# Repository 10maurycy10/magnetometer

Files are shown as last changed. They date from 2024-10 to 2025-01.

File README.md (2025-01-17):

# Fluxgate magnetometer datalogger

Data is logged to a microSD/SDHC/SDXC card, which must support SPI mode.
It should be formated as FAT12, FAT16, FAT32 or ExFAT.
If it has an MBR partion table, the first partion will be used.

Most sub 2 TB cards should work as is.

Data is logged to `FLUXGATE.CSV`, in a CSV format.

|First field|Second field format|Notes|
|-|-|-|
|empty string|empty string|Startup banner, includes third field with human readable comment|
|`Vdiv`|Int (mV)|Measured voltage on the Vdd/2 rail of the opamp filter, written on startup.|
|`Vamp`|Int (mV)|Measured amplifier output voltage, written on startup|
|`Vdiv`|Int (mV)|Measure diffence between Vdd/2 and output, written on startup|
|`OSR`|Int|Oversampling ratio used for measurements|
|`Tlog`|Int (ms)|Time between measurements|
|Int|Int|Field measurements, first field is a counter that increments with each one.|

$$ \text{Reading} = \text{Peak-Peak voltage (mV)} \times 10 \times \text{OSR} $$

# Hardware

It should be able to drive most fluxgates, but I got the best result with a [high permiability, square-loop core](https://www.digikey.com/en/products/detail/toshiba-semiconductor-and-storage/MS21X14X4-5W/4701157)
using the classic ring core configuration:
The drive coil was wound around the entire core, and the sense coil was wound on a 3d printed bobin placed over the core:

 
 
With the high gain of the amplifier, the earth's magnetic field (50 uT at my place) is enough to saturate the sensor. 
Alternativly, the compensation driver can be enabled to cancel out the field, but the driver can only push current in one direction, so the sensor might have to be flipped for this to work.

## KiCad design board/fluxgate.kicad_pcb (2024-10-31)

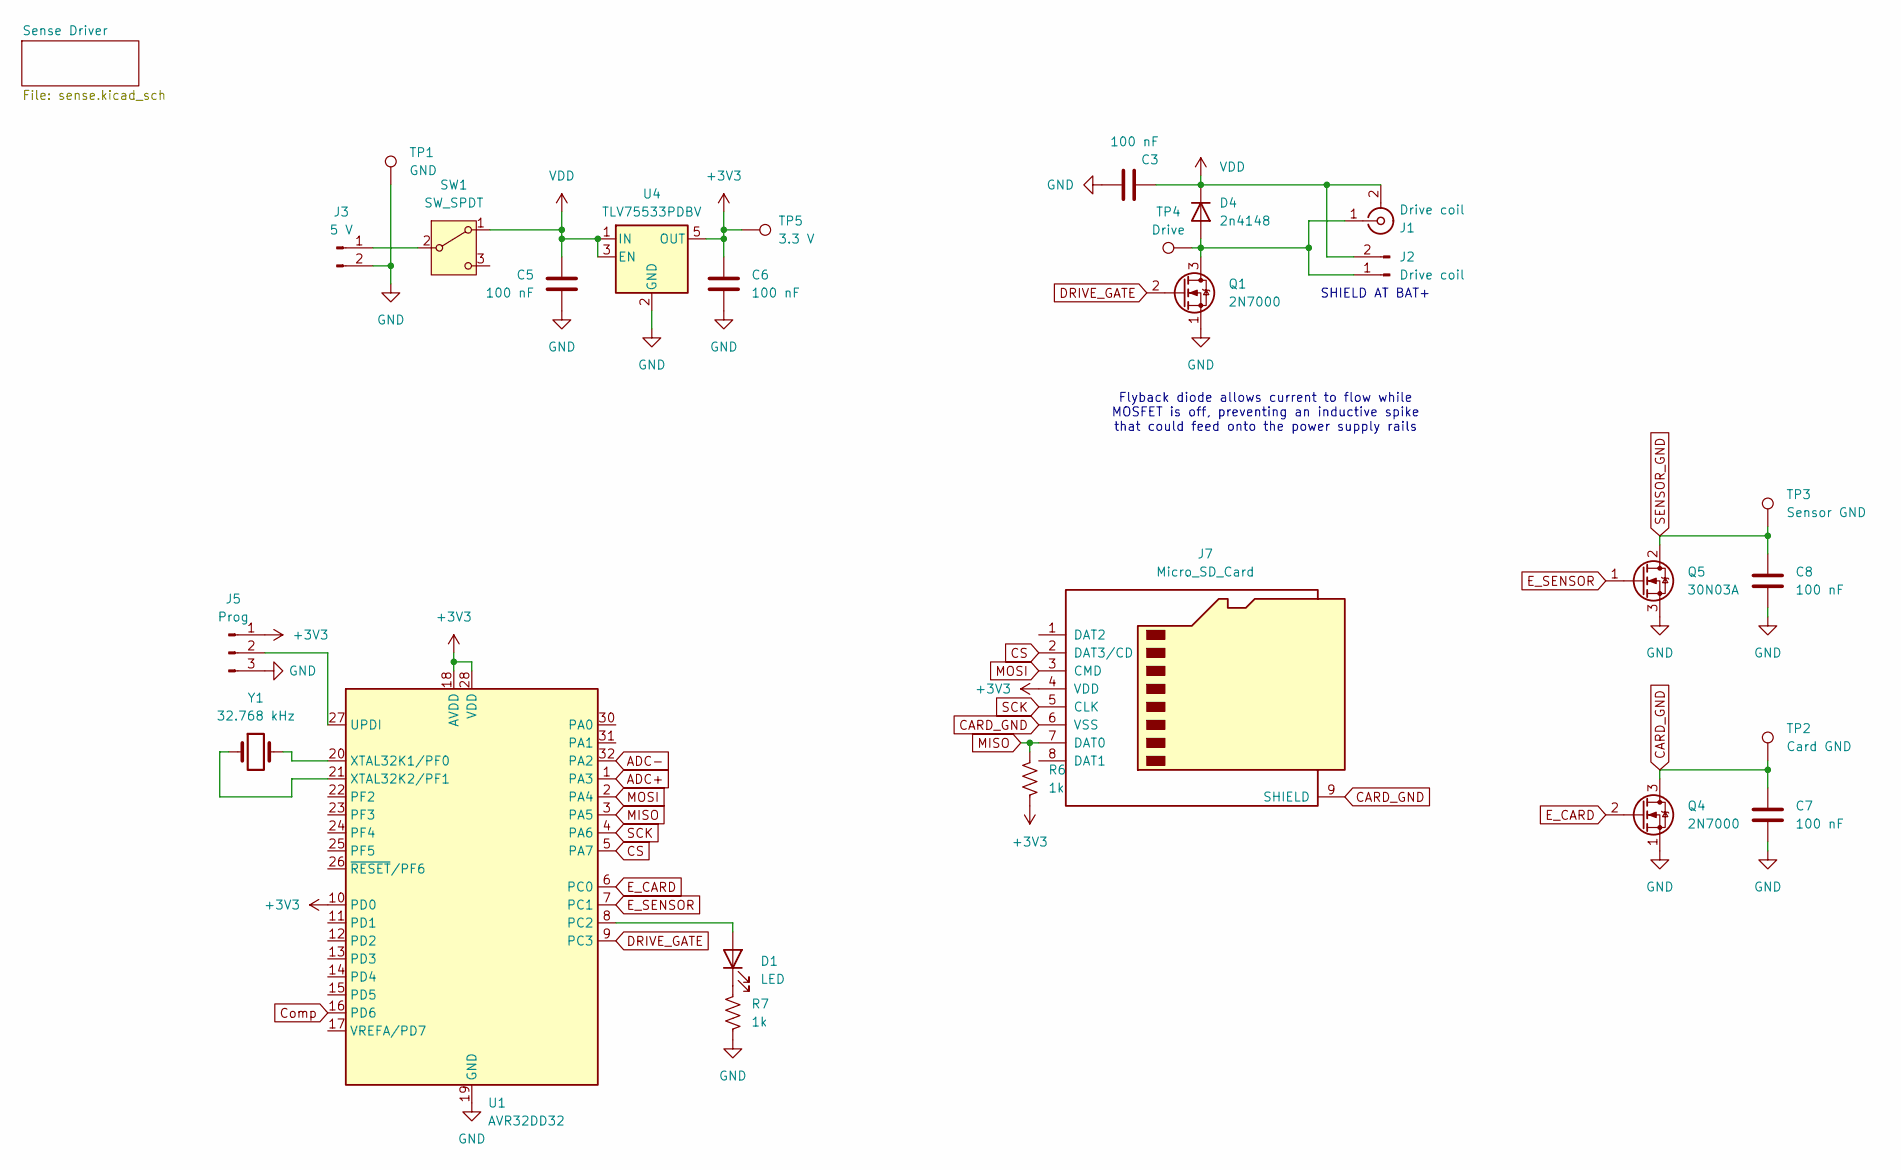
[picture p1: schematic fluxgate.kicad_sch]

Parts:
C3, C5, C6, C7, C8: 100 nF; C_Disc_D3.4mm_W2.1mm_P2.50mm
D1: LED; LED_D3.0mm
D4: 2n4148; D_DO-34_SOD68_P7.62mm_Horizontal
J1: Drive coil; SMA_Amphenol_132289_EdgeMount
J2: Drive coil; PinHeader_1x02_P2.54mm_Vertical
J3: 5 V; PinHeader_1x02_P2.54mm_Vertical
J5: Prog; PinHeader_1x03_P2.54mm_Vertical
J7: Micro_SD_Card; microSD_HC_Molex_104031-0811
Q1, Q4: 2N7000; TO-92_Inline
Q5: 30N03A; TO-252-2
R6, R7: 1k; R_Axial_DIN0207_L6.3mm_D2.5mm_P10.16mm_Horizontal
SW1: SW_SPDT; SW_E-Switch_EG1271_SPDT
TP1: GND; TestPoint_Keystone_5015_Micro-Minature
TP2: Card GND; TestPoint_Keystone_5015_Micro-Minature
TP3: Sensor GND; TestPoint_Keystone_5015_Micro-Minature
TP4: Drive; TestPoint_Keystone_5015_Micro-Minature
TP5: 3.3 V; TestPoint_Keystone_5015_Micro-Minature
U1: AVR32DD32; TQFP-32_7x7mm_P0.8mm
U4: TLV75533PDBV; SOT-23-5
Y1: 32.768 kHz; Crystal_HC52-8mm_Vertical

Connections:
+3V3: C6.2, J5.1, J7.4 (VDD), R6.2, TP5.1, U1.10 (PD0), U1.18 (AVDD), U1.28 (VDD), U4.5 (OUT); also elsewhere on the board
ADC+: U1.1 (PA3); also elsewhere on the board
ADC-: U1.32 (PA2); also elsewhere on the board
CARD_GND: C7.1, J7.6 (VSS), J7.9 (SHIELD), Q4.3 (D), TP2.1
CS: J7.2 (DAT3/CD), U1.5 (PA7)
Comp: U1.16 (PD6); also elsewhere on the board
DRIVE_GATE: Q1.2 (G), U1.9 (PC3)
E_CARD: Q4.2 (G), U1.6 (PC0)
E_SENSOR: Q5.1 (G), U1.7 (PC1)
GND: C3.2, C5.1, C6.1, C7.2, C8.2, J3.2, J5.3, Q1.1 (S), Q4.1 (S), Q5.3 (S), R7.2, TP1.1, U1.19 (GND), U1.29 (GND), U4.2 (GND); also elsewhere on the board
MISO: J7.7 (DAT0), R6.1, U1.3 (PA5)
MOSI: J7.3 (CMD), U1.2 (PA4)
unnamed: D1.2 (A), U1.8 (PC2)
unnamed: D1.1 (K), R7.1
unnamed: D4.2 (A), J1.1 (In), J2.1, Q1.3 (D), TP4.1
unnamed: J3.1, SW1.2 (B)
unnamed: J5.2, U1.27 (UPDI)
unnamed: U1.20 (XTAL32K1/PF0), Y1.2
unnamed: U1.21 (XTAL32K2/PF1), Y1.1
SCK: J7.5 (CLK), U1.4 (PA6)
SENSOR_GND: C8.1, Q5.2 (D), TP3.1; also elsewhere on the board
VDD: C3.1, C5.2, D4.1 (K), J1.2 (Ext), J2.2, SW1.1 (A), U4.1 (IN), U4.3 (EN)

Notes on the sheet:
SHIELD AT BAT+
Flyback diode allows current to flow while MOSFET is off, preventing an inductive spike that could feed onto the power supply rails

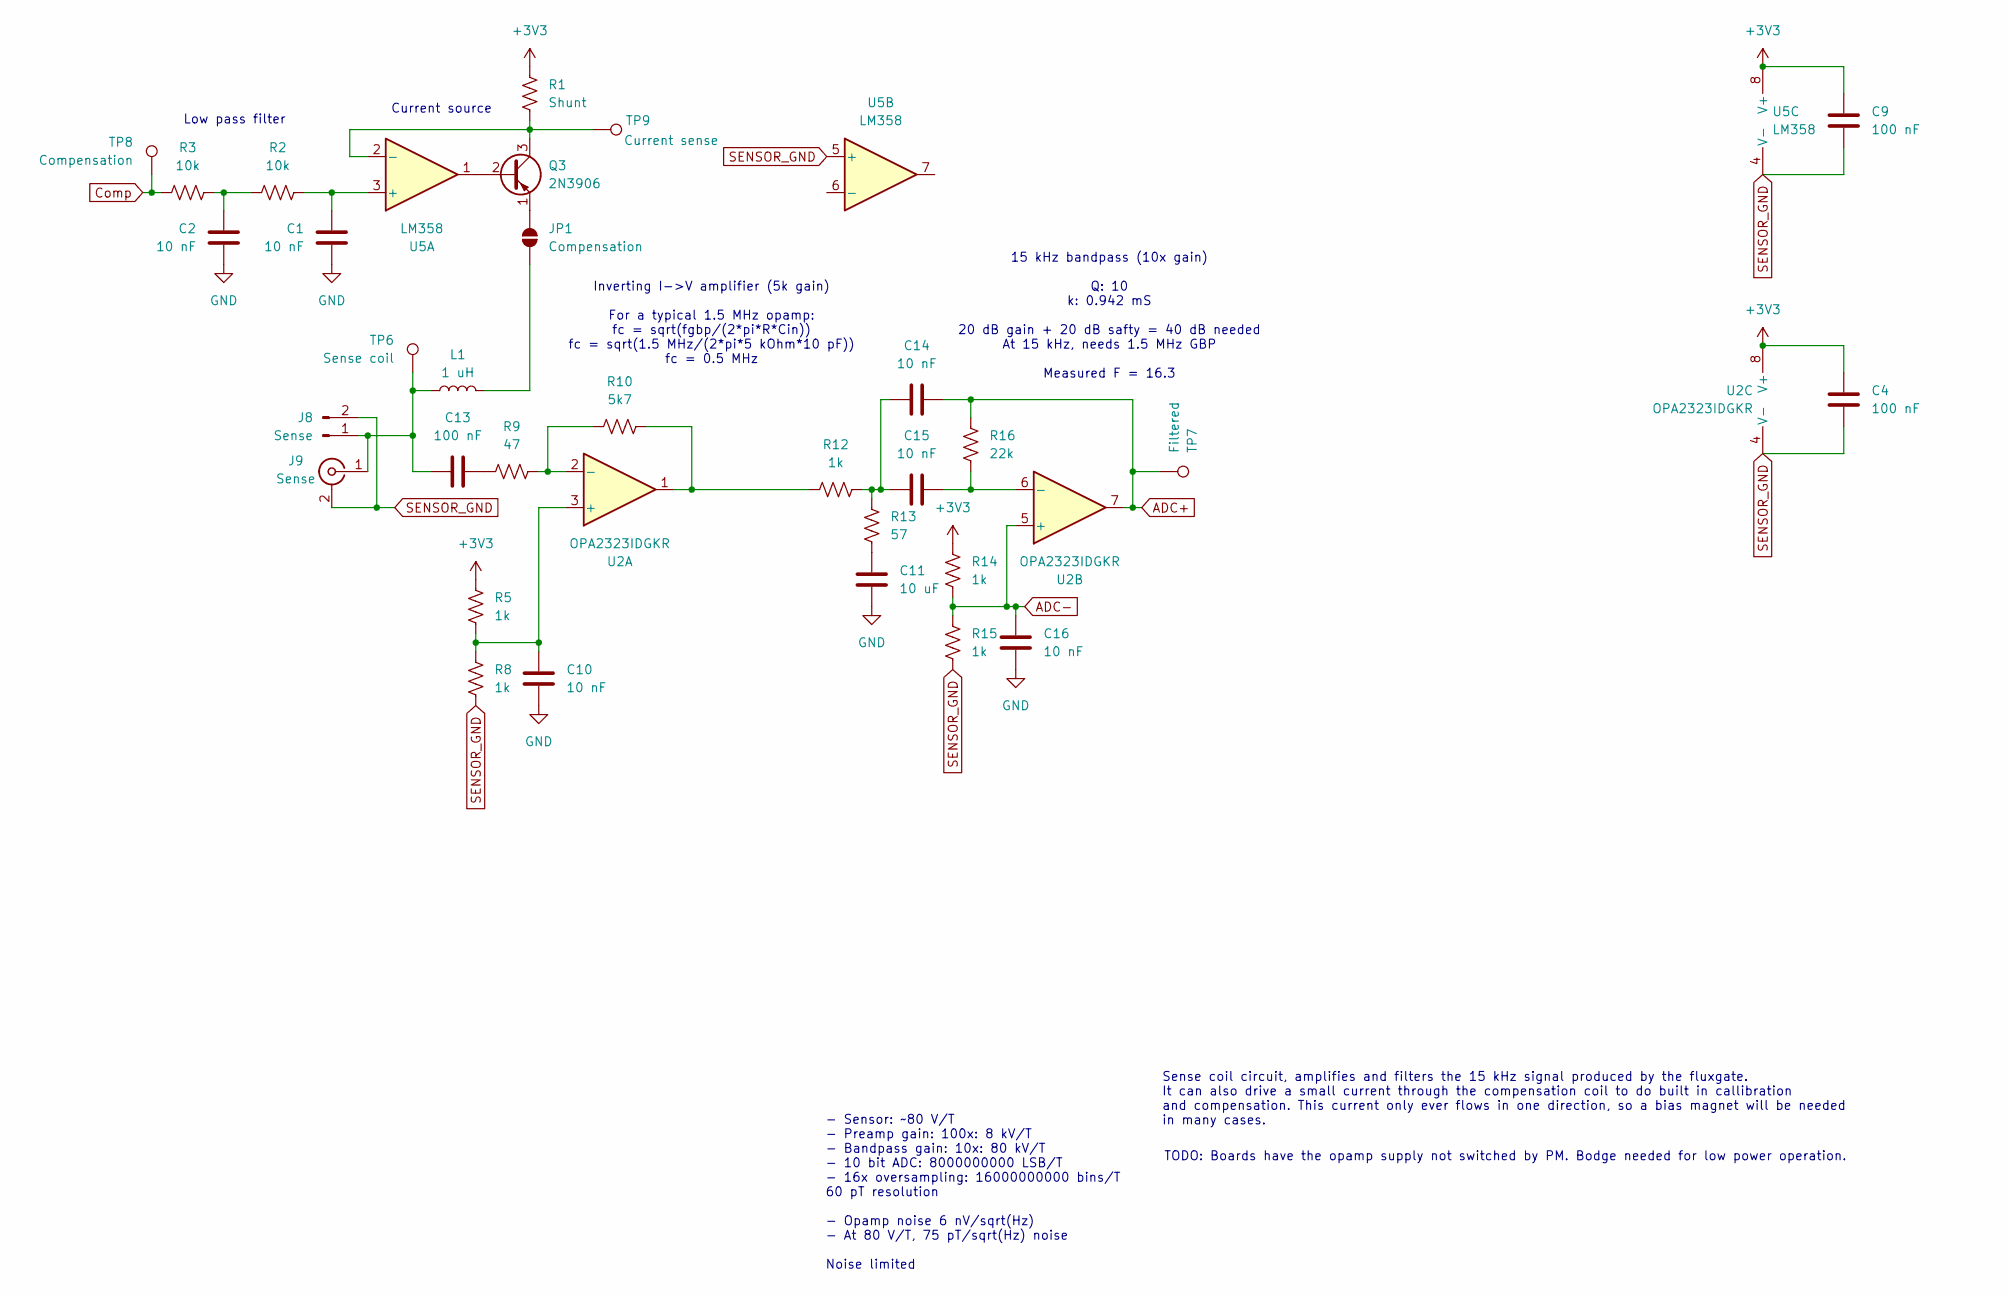
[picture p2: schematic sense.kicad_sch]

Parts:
C1, C2, C10, C14, C15, C16: 10 nF; C_Disc_D3.4mm_W2.1mm_P2.50mm
C4, C9, C13: 100 nF; C_Disc_D3.4mm_W2.1mm_P2.50mm
C11: 10 uF; C_Disc_D3.4mm_W2.1mm_P2.50mm
J8: Sense; PinHeader_1x02_P2.54mm_Vertical
J9: Sense; SMA_Amphenol_132289_EdgeMount
JP1: Compensation; SolderJumper-2_P1.3mm_Open_RoundedPad1.0x1.5mm
L1: 1 uH; L_Radial_D7.2mm_P3.00mm_Murata_1700
Q3: 2N3906; TO-92_Inline
R1: Shunt; R_Axial_DIN0207_L6.3mm_D2.5mm_P10.16mm_Horizontal
R2, R3: 10k; R_Axial_DIN0207_L6.3mm_D2.5mm_P10.16mm_Horizontal
R5, R8, R12, R14, R15: 1k; R_Axial_DIN0207_L6.3mm_D2.5mm_P10.16mm_Horizontal
R9: 47; R_Axial_DIN0207_L6.3mm_D2.5mm_P10.16mm_Horizontal
R10: 5k7; R_Axial_DIN0207_L6.3mm_D2.5mm_P10.16mm_Horizontal
R13: 57; R_Axial_DIN0207_L6.3mm_D2.5mm_P10.16mm_Horizontal
R16: 22k; R_Axial_DIN0207_L6.3mm_D2.5mm_P10.16mm_Horizontal
TP6: Sense coil; TestPoint_Keystone_5015_Micro-Minature
TP7: Filtered; TestPoint_Keystone_5015_Micro-Minature
TP8: Compensation; TestPoint_Keystone_5015_Micro-Minature
TP9: Current sense; TestPoint_Keystone_5015_Micro-Minature
U2: OPA2323IDGKR; SOIC-8W_5.3x5.3mm_P1.27mm
U5: LM358; SOIC-8W_5.3x5.3mm_P1.27mm

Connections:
+3V3: C4.2, C9.2, R1.1, R5.2, R14.2, U2.8 (V+), U5.8 (V+); also elsewhere on the board
ADC+: C14.2, R16.2, TP7.1, U2.7; also elsewhere on the board
ADC-: C16.2, R14.1, R15.2, U2.5 (+); also elsewhere on the board
Comp: R3.1, TP8.1; also elsewhere on the board
GND: C1.1, C2.1, C10.1, C11.1, C16.1; also elsewhere on the board
unnamed: C2.2, R2.1, R3.2
unnamed: C11.2, R13.1
unnamed: C13.2, R9.1
unnamed: C14.1, C15.1, R12.2, R13.2
unnamed: C13.1, J8.1, J9.1 (In), L1.1, TP6.1
unnamed: JP1.1 (A), L1.2
unnamed: JP1.2 (B), Q3.1 (E)
unnamed: Q3.2 (B), U5.1
unnamed: Q3.3 (C), R1.2, TP9.1, U5.2 (-)
unnamed: R10.2, R12.1, U2.1
unnamed: C10.2, R5.1, R8.2, U2.3 (+)
unnamed: R9.2, R10.1, U2.2 (-)
unnamed: C15.2, R16.1, U2.6 (-)
unnamed: C1.2, R2.2, U5.3 (+)
SENSOR_GND: C4.1, C9.1, J8.2, J9.2 (Ext), R8.1, R15.1, U2.4 (V-), U5.4 (V-), U5.5 (+); also elsewhere on the board

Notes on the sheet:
- Sensor: ~80 V/T - Preamp gain: 100x: 8 kV/T - Bandpass gain: 10x: 80 kV/T - 10 bit ADC: 8000000000 LSB/T - 16x oversampling: 16000000000 bins/T 60 pT resolution - Opamp noise 6 nV/sqrt(Hz) - At 80 V/T, 75 pT/sqrt(Hz) noise Noise limited
Inverting I->V amplifier (5k gain) For a typical 1.5 MHz opamp: fc = sqrt(fgbp/(2*pi*R*Cin)) fc = sqrt(1.5 MHz/(2*pi*5 kOhm*10 pF)) fc = 0.5 MHz
Low pass filter
Sense coil circuit, amplifies and filters the 15 kHz signal produced by the fluxgate. It can also drive a small current through the compensation coil to do built in callibration and compensation. This current only ever flows in one direction, so a bias magnet will be needed in many cases.
TODO: Boards have the opamp supply not switched by PM. Bodge needed for low power operation.
15 kHz bandpass (10x gain) Q: 10 k: 0.942 mS 20 dB gain + 20 dB safty = 40 dB needed At 15 kHz, needs 1.5 MHz GBP Measured F = 16.3
Current source

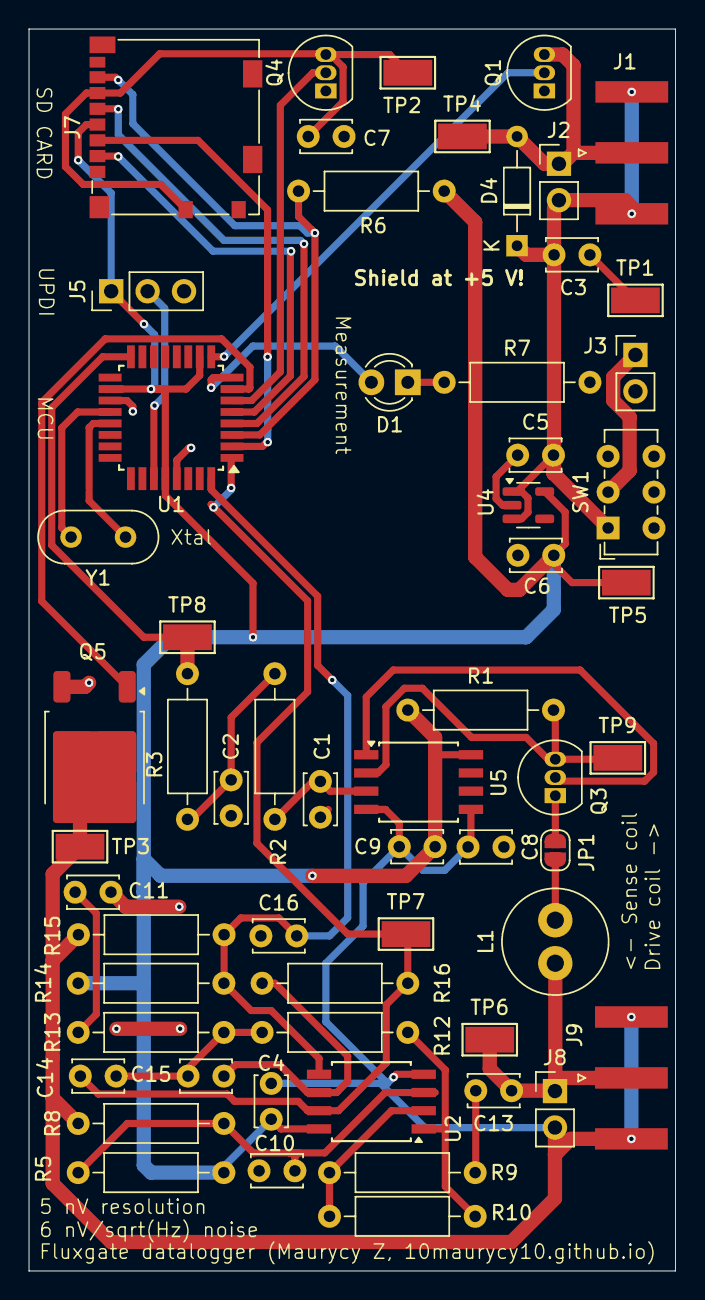
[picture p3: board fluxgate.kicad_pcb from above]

Board: 2 copper layers, 45.1 x 86.6 mm, 59 parts (0 on the bottom side), 36 nets.

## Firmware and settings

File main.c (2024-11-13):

#include <stdint.h>
#include <avr/io.h>
#include <avr/delay.h>
#include "fs/ff.h"
#include "fs/diskio.h"

// TODO:
// Large OSR's
// Low power sleep mode (slow clock)
// Power off SD

void sd_power_off();

#define PORTC_E_CARD (1 << 0)
#define PORTC_E_SENSOR (1 << 1)
#define PORTC_LED (1 << 2)
#define PORTC_DRIVE_COIL (1 << 3)

#define PORTA_CS (1 << 7)

uint32_t log_interval = 1000; // ms
int oversampling_ratio = 47; // Chosen to null out 60 Hz interference

// 0: Sum up OSR samples
// 1: Record OSR independant samples
int burst_mode = 0;
#define MAX_BURST 512
int16_t burst_buffer[MAX_BURST]; 

FATFS fs;
FIL fd;

void read_config() {
	FIL config;
	if (f_open(&config, "FLUXGATE.CFG", FA_READ)) return;

	int32_t value;
	uint16_t len;
	
	// Read log interval
	f_read(&config, &value, sizeof(int32_t), &len);
	if (len > 0) log_interval = value;
	
	// Reading oversampling ratio
	f_read(&config, &value, sizeof(int32_t), &len);
	if (len > 0) oversampling_ratio = value;
	
	// Burst mode
	f_read(&config, &value, sizeof(int32_t), &len);
	if (len > 0) burst_mode = value;
	
	if (oversampling_ratio > MAX_BURST) oversampling_ratio = MAX_BURST;

	f_close(&config);
}

// Flash LED at 5 Hz indicate problem with uSD
void sd_timeout() {
	while (1) {
		PORTC.OUT ^= PORTC_LED;
		_delay_ms(100);
	}
}

// Flash LED 3 times to indicate saturation
void saturated(){
	for (int i = 0; i < 3; i++) {
		PORTC.OUTSET = PORTC_LED;
		_delay_ms(50);
		PORTC.OUTCLR = PORTC_LED;
		_delay_ms(50);
	}
}

// Two quick flashes then delay
void self_test_failure() {
	f_printf(&fd, ",,Self test failed. Giving up.\n"); 
	f_close(&fd);
	sd_power_off(); // Ensure that the log file is written
	while (1) {
		PORTC.OUTSET = PORTC_LED;
		_delay_ms(100);
		PORTC.OUTCLR = PORTC_LED;
		_delay_ms(100);
		PORTC.OUTSET = 1 << 2;
		_delay_ms(100);
		PORTC.OUTCLR = 1 << 2;
		_delay_ms(500);
	}
}

///////////////////////////////////////////////////////////////////////////////
//                                                                           //
// Low level memory card driver, supports MMC (untested) SDSC, SDHC, and     //
// SDXC cards. Always uses a block size of 512 (0x200) bytes regardless of   //
// the card used. The flash inside usually has a block size of 512 or higher,//
// so this doesn't impact lifespan.                                          //
//                                                                           //
///////////////////////////////////////////////////////////////////////////////

uint8_t sd_xfer(uint8_t data) {
	SPI0.DATA = data;
	while (~SPI0.INTFLAGS & 1 << 7) ;
	SPI0.INTFLAGS = 1 << 7;
	return SPI0.DATA;
}


// Read an R1 response, the other responces are just R1 with some data 
// tacked on, which can be read with sd_xfer(). 
uint8_t sd_get_r1() {
	uint16_t count = 0;
	while (1) {
		uint8_t r1 = sd_xfer(0xff);
		if (r1 != 0xFF) return r1;
		if (count > 16000) sd_timeout();
		_delay_us(10);
		count++; 
	}
}

// Returns 1 if a valid, error free response is given, 0 on errors or timeout.
// This is mostly used for checking the card's compatability.
uint8_t sd_check_r1() {
	uint16_t count = 0;
	while (1) {
		uint8_t r1 = sd_xfer(0xff);
		if (r1 == 0x0 || r1 == 0x1) return 1;
		if (r1 != 0xff) return 0;
		if (count > 16000) return 0;
		_delay_us(10);
		count++; 
	}
}

// Send a command to the card.
// The CRC will be ingored once initialized, but a correct checksum
// is needed during initilization.
void sd_command(uint8_t cmd, uint32_t arg, uint8_t crc) {
	sd_xfer(cmd|0x40);
	sd_xfer((uint8_t)(arg >> 24));
	sd_xfer((uint8_t)(arg >> 16));
	sd_xfer((uint8_t)(arg >> 8));
	sd_xfer((uint8_t)(arg));
	sd_xfer(crc|0x01);
}

// Mostly universal initization function, configures the card to use 512 byte blocks
// if it doesn't already.
void sd_init() {
	uint8_t is_v2 = 0, is_byte_addressed = 0;

	PORTA.DIRSET = 1 << 4 | 1 << 5 | 1 << 6 | 1 << 7; 
	PORTC.OUTCLR = PORTC_E_CARD; // Do a power cycle to ensure a known state.
	_delay_ms(10);
	PORTC.OUTSET = PORTC_E_CARD;
	_delay_ms(10);
	PORTA.OUTSET = PORTA_CS;
	_delay_ms(10);

	// Send 80 clock cycles with the card deselected
	// This lets the card know we're ready to start sending data.
	for (int i = 0; i < 10; i++) sd_xfer(0xff);
	_delay_ms(1);

	// CMD0: Software reset
	PORTA.OUTCLR = PORTA_CS;
	_delay_ms(1);
	sd_command(0, 0, 0x94);
	_delay_ms(1);
	sd_get_r1();

	// CMD8: Voltage check
	// This will work on newer V2 cards, but will fail on V1 or MMC cards.
	sd_command(8, 0x1AA, 0x87);
	if (sd_check_r1()) {
		// If it worked, read back the echoed response.
		// If this data is wrong, there is probobly an issue with the connection.
		is_v2 = 1;
		if (sd_xfer(0xFF) != 0x00) sd_timeout();
		if (sd_xfer(0xFF) != 0x00) sd_timeout();
		if (sd_xfer(0xFF) != 0x01) sd_timeout();
		if (sd_xfer(0xFF) != 0xAA) sd_timeout();
	} else {
		// If it didn't we have a V1 or MMC card, either way it uses byte addressing by default
		is_byte_addressed = 1;
	}

	// Use ACMD41 (CMD55+CMD41) to initialize the card. This will fail on MMC cards.
	// This always takes a few attemps, I don't really know why.
	int done = 0;
	int timeout = 1000; // 1 second
	while (!done) {
		// Give up if the card doesn't initialize
		timeout--;
		if (timeout == 0) sd_timeout(); 
		_delay_ms(1);
		
		// ACMD 41. 
		sd_command(55, 0x0, 0x65);
		if (!sd_check_r1()) {
			// If ACMD 41 failed, the card only supports MMC
			// Initilization has to be done with CMD1.
			while (!done) {
				sd_command(1, 0x0, 0);
				if (sd_get_r1() == 0x01) {
					timeout--;
					if (timeout == 0) sd_timeout(); 
				} else {
					done = 1;
				}
			}
			// MMC initization done, no need to keep trying SD setup.
			break;
		}
		sd_command(41, 0x40000000, 0x77);
		
		uint8_t status = sd_get_r1();
		if (status == 0x00) done = 1;
		else if (status == 0x01) continue;
		else sd_timeout(); // Broken or very old card. 
	}

	// Some V2 cards use byte addressing, we have to check.
	if (is_v2) {	
		sd_command(48, 0x0, 0x65);	
		sd_get_r1(); // First byte is reserved
		uint8_t OCR[4];
		OCR[0] = sd_xfer(0xFF);
		OCR[1] = sd_xfer(0xFF);
		OCR[2] = sd_xfer(0xFF);
		OCR[3] = sd_xfer(0xFF);
		sd_xfer(0xFF); // Final byte is reseved
		// Bit 30 of the OCR is set for block addressed cards (HC/XC)
		is_byte_addressed = !(OCR[0] >> 6) & 1;
	}

	// If the card supports byte addressing, set the block size to 512 for
	// consitancy with the always block addressed cards (SDHC and higher)
	if (is_byte_addressed) {
		sd_command(16, 0x200, 0x0);
		sd_get_r1();
	}
}

// Disconnect power from the SD card to improve battery life.
void sd_power_off() {
	// Make sure the card has time to finish operations
	for (int i = 0; i < 10; i++) sd_xfer(0xFF);
	_delay_ms(5); // T

//	TODO FIXME	
	PORTC.OUTCLR = PORTC_E_CARD;
//	_delay_ms(1);
//	PORTA.DIRCLR = 1 << 4 | 1 << 5 | 1 << 6 | 1 << 7; 
}

// Low level read and write primitives
void read_block(uint8_t* buff, uint32_t sector) {
	// Send read command
	sd_command(17, sector, 0);
	sd_get_r1();
	
	// Recieve data
	if (sd_get_r1() != 0xfe) sd_timeout();
	for (int i = 0; i < 512; i++) {
		buff[i] = sd_xfer(0xff);
	}
	
	// Discard the CRC
	sd_xfer(0xff); sd_xfer(0xff);
}

void write_block(uint8_t* buff, uint32_t sector) {
	// Send write command
	sd_command(24, sector, 0);
	sd_get_r1();
	
	// Give it some time before sending data
	sd_xfer(0xff); 
	
	// Send the start token
	sd_xfer(0b11111110);
	
	// Send the data
	for (int i = 0; i < 0x200; i++) {
		sd_xfer(buff[i]);
	}
	
	// Send dummy CRC
	sd_xfer(0xff); sd_xfer(0xff);

	// Wait for completion
	sd_get_r1();
	while (sd_xfer(0xff) == 0x00) ; 
}

//////////////////////////////////////////////////////////////////////////////
//                                                                          //
// Filesystem driver interface, called by the FatFs library in fs/.         //
//                                                                          //
//////////////////////////////////////////////////////////////////////////////

// We'll manualy initialize the card before mounting
DSTATUS disk_initialize (BYTE pdrv) {return 0;}

// Multiblock read. We don't care about speed, so using a bunch of single
// block commands is just fine.
DRESULT disk_read (BYTE drive, BYTE* buff, LBA_t sector, UINT count) {
	for (int i = 0; i < count; i++) {
		read_block(&buff[512*i], sector + i);
	}
	return 0;
};


// Multiblock write. We don't care about speed, so using a bunch of single
// block commands is just fine.
DRESULT disk_write (BYTE drive, const BYTE* buff, LBA_t sector, UINT count) {
	for (int i = 0; i < count; i++) {
		write_block(&buff[0x200*i], sector);
	}
	return 0;
};

// This function tells the library the block size for reading (SECTOR_SIZE)
// and writing (BLOCK_SIZE, in multiples of SECTOR_SIZE)
DRESULT disk_ioctl (BYTE pdrv, BYTE cmd, void* buff) {
	if (cmd == GET_SECTOR_SIZE) *((WORD*)buff) = 0x200;
	if (cmd == GET_BLOCK_SIZE) *((DWORD*)buff) = 1;
	return 0;
}

// The read/write primitives are blocking, nothing to do here.
DSTATUS disk_status (BYTE pdrv) {
	return 0; 
}

// Without an RTC, we have no way of knowing the real time, so 
// just use an blatantly bogus date (1980)
DWORD get_fattime (void) {
	return 0; // don't have a clock :(
}

//////////////////////////////////////////////////////////////////////////////
//                                                                          //
// Magnetic field measurement.                                              //
//                                                                          //
//////////////////////////////////////////////////////////////////////////////


void adc_setup() {
	VREF.ADC0REF = 0x0; // Internal 1.024 V reference
	ADC0.CTRLA = 0x1 << 5 | 0x1; // Diff, enable
	ADC0.CTRLB = 0x0; // Single shot
	ADC0.CTRLC = 0x0; // Div/2
	ADC0.CTRLE = 0x0; // No comparitor
	ADC0.MUXPOS = 23; // AIN 23 
	ADC0.MUXNEG = 22; // AIN 22
}


// Sanity check for the ciruict
// Measurements are taken multiple times to check for bad (high-z) connections.
void self_test() {
	adc_setup();
	PORTC.OUTSET = PORTC_E_SENSOR;
	_delay_ms(50);

	// Read voltage divider
	VREF.ADC0REF = 1; // 2.048 V reference
	ADC0.MUXPOS = 22; // AIN 22
	ADC0.MUXNEG = 0x40; // GND
	for (int i = 0; i < 50; i++) {
		ADC0.COMMAND = 1;
		while (ADC0.COMMAND) ;
	}
	int16_t vdiv = ADC0.RES;
	f_printf(&fd, "Vdiv,%d\n", vdiv); 

	// Read amplifier output
	VREF.ADC0REF = 1; // 2.048 V reference
	ADC0.MUXPOS = 23; // AIN 23
	ADC0.MUXNEG = 0x40; // GND
	for (int i = 0; i < 50; i++) {
		ADC0.COMMAND = 1;
		while (ADC0.COMMAND) ;
	}
	int16_t vamp = ADC0.RES;
	f_printf(&fd, "Vamp,%d\n", vamp); 
	
	// Read difference
	VREF.ADC0REF = 1; // 2.048 V reference
	ADC0.MUXPOS = 23; // AIN 23
	ADC0.MUXNEG = 22; // AIN 22
	for (int i = 0; i < 50; i++) {
		ADC0.COMMAND = 1;
		while (ADC0.COMMAND) ;
	}
	int16_t vdiff = ADC0.RES;
	f_printf(&fd, "Vdiff,%d\n", vdiff); 
	
	
	// Turn off the amplifier
	PORTC.OUTCLR = PORTC_E_SENSOR;
	
	// Fluxh file
	f_sync(&fd);

	// With a 2.048 volt reference and 2048 bins per vref, the output is will be in mV
	int32_t expected = 1560; 
	if (vdiv > (expected + 200) || vdiv < (expected - 200)) self_test_failure();
	if (vamp > (expected + 200) || vamp < (expected - 200)) self_test_failure();
	if (vdiff > 50 || vdiff < -50) self_test_failure();
}

// Results are stored in burst_buffer
void measure(int count) {
	PORTC.OUTSET = PORTC_E_SENSOR;
	adc_setup(); // Reset ADC for 1 volt (.5 mV res) differential mode
	_delay_ms(10); // Givw the sensor time to start
	
	int n = 0; // Number of samples recorded
	int i = -10; // Number of half-cycles in the current sample	
	int sign = 1; // Current phase of the drive coil
	volatile int16_t accumulator = 0;

	while (n < count) {
		PORTC.OUT ^= PORTC_LED;
		ADC0.COMMAND = 1;
		_delay_us(18); 
		PORTC.OUT ^= PORTC_DRIVE_COIL;
		
		// Record samples every 5 cycles
		if (i == 10) {
			burst_buffer[n] = accumulator;
			accumulator = 0;
			i = 0;
			n++;
		}

		// Record measurement
		accumulator += ADC0.RES * sign;
		if (i < 0) accumulator = 0;
		
		sign *= -1;
		i++;
	}

	PORTC.OUTCLR = PORTC_LED;
	PORTC.OUTCLR = PORTC_DRIVE_COIL;
	PORTC.OUTCLR = PORTC_E_SENSOR;
}


//////////////////////////////////////////////////////////////////////////////
//                                                                          //
// Measurement modes                                                        //
//                                                                          //
//////////////////////////////////////////////////////////////////////////////

uint32_t lines_written = 0;

// Add up a bunch of measurements together to minize noise
void oversample(int times) {
	measure(times);

	int32_t acc = 0;
	for (int i = 0; i < times; i++) acc += burst_buffer[i];
	
	int32_t avg = (acc / times / 5);
	if (avg < 0) avg *= -1;
	if (avg > 1800) saturated();
	
	sd_init();
	f_printf(&fd, "%ld,%ld\n", lines_written, acc); 
	f_sync(&fd);
	lines_written++;	
	sd_power_off();
}

// Dump all the raw measurements to allow recording AC fields
void burst(int times) {
	measure(times);

	int is_saturated = 0;

	sd_init();
	f_printf(&fd, "%ld,", lines_written); 
	for (int i = 0; i < times; i++) {
		f_printf(&fd, "%d,", burst_buffer[i]); 
		if (burst_buffer[i] > 1800 * 5) is_saturated = 1;
		if (burst_buffer[i] < -1800 * 5) is_saturated = 1;
	}
	f_printf(&fd, "\n"); 
	
	// Flash LED if sensor saturated during burst 
	if (is_saturated) saturated();

	f_sync(&fd);
	lines_written++;	
	sd_power_off();
}

//////////////////////////////////////////////////////////////////////////////
//                                                                          //
// Main loop.                                                               //
//                                                                          //
//////////////////////////////////////////////////////////////////////////////



void write_banner() {
	f_puts("\n,,Fluxgate datalogger: restarted.\n", &fd);
	f_printf(&fd, "Tlog,%ld\n", log_interval);
	f_printf(&fd, "OSR,%d\n", oversampling_ratio);
	f_sync(&fd);
}

int main(void) {
	PORTC.DIRSET = 0xFF; // LED + Drive coil + PM mosfets

	PORTA.DIRSET = 1 << 4 | 1 << 5 | 1 << 6 | 1 << 7; // Sd card spi pins
	SPI0.CTRLA = 1 << 5 | 0x3 << 1 | 1; // SPI: Master, max prescaler, enabled

	adc_setup();
	
	// Mount the card, read config and open log file
	sd_init();
	if (f_mount(&fs, "", 1)) sd_timeout();
	read_config();
	if (f_open(&fd, "/FLUXGATE.CSV", FA_WRITE | FA_OPEN_APPEND)) sd_timeout();
	write_banner();

	// Run self test, this writes to the card
	self_test();
	
	// Turn off the card to conserve power.
	sd_power_off();

	// Max = ~33 seconds
	TCA0.SINGLE.PER = log_interval * 1959 / 1000;
	TCA0.SINGLE.CTRLA = 0b10001111; // clk_per/1024 = 1.953 kHz
	
	// Loggging loop
	while (1) {
		// Wait for timer to overflow
		while (~TCA0.SINGLE.INTFLAGS & 1) ;
		TCA0.SINGLE.INTFLAGS = 1;

		// Record field reading
		_delay_ms(10);
		if (burst_mode) {
			burst(oversampling_ratio);
		} else {
			oversample(oversampling_ratio);
		}
		PORTC.OUTCLR = PORTC_DRIVE_COIL | PORTC_E_SENSOR;
	}

	return 0;
}

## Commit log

2024-10-30 Board ok
    [fluxgate-B_Cu.gbr, fluxgate-B_Mask.gbr, fluxgate-B_Paste.gbr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]
2024-10-31 Fix filesystem, writing files works now
    [main.c]
2024-10-31 Start working on measurement
    [fluxgate.kicad_pcb, fluxgate.kicad_sch]
2024-11-03 Select optimal OSR for noise rejection
    [main.c]
